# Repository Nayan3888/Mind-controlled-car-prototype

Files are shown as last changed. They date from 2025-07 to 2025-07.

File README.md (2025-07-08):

# 🧠🚗 Mind-Controlled Car using EEG and IoT

A smart **EEG-based Mind-Controlled Car** system that uses the **NeuroSky MindWave Mobile 2** headset to interpret brainwave signals and control an **ESP32-based robot car** via Bluetooth and HTTP protocols. The system also includes **manual control options** using IR remotes and physical buttons, making it a hybrid multi-input system.

---

## 🚀 Project Overview

This project demonstrates how **EEG (Electroencephalography) signals** can be used to control a robotic vehicle. The headset detects **attention, meditation, and blinks**, which are processed in a **Flutter app** to make real-time movement decisions. The car is then controlled via **Wi-Fi (ESP32 HTTP)** based on the detected mental commands.

---

## 🧩 Features

* 🔗 **Real-time EEG signal processing** from NeuroSky MindWave
* 📱 **Flutter mobile app** for Bluetooth communication and UI
* 🌐 **Wi-Fi-based car control** using ESP32 (HTTP GET/POST)
* 👀 **Blink detection** to trigger left/right movement
* 🧘 **Meditation level** to control reverse
* 🚘 Manual controls via:

  * 📡 IR Remote
  * 🔘 Push buttons on PCB
* 📈 Real-time brainwave data graph (Alpha, Beta, Gamma, etc.)
* 🔌 Power-efficient and multi-mode operation

---

## 🛠️ Hardware Components

| Component | Description |
| --- | --- |
| 🧠 NeuroSky MindWave | EEG Headset |
| 🔲 ESP32-WROOM-32 | Microcontroller with Wi-Fi |
| 📱 Android Phone | For Flutter App and EEG parsing |
| 🛞 L298N Motor Driver | For dual DC motor control |
| 🔋 Battery | For powering motors and board |
| 🔘 IR Receiver + Remote | Manual car control |
| 📟 16x2 I2C LCD | (Optional) Display EEG/Status |
| 💧 Moisture/pH Sensor | (Optional extension) |

---

## 📲 Flutter App Features

* Scan and connect to MindWave EEG device (BLE)
* Graphically display EEG metrics (attention, meditation, blink strength)
* Send movement commands to ESP32 via Wi-Fi
* Real-time feedback and alerts

---

## 🔧 How It Works

1. MindWave reads brain signals.
2. Flutter app parses EEG data over Bluetooth using `flutter_blue_plus`.
3. Based on blink or meditation thresholds:

   * Sends commands (e.g., `FORWARD`, `LEFT`, `REVERSE`) to ESP32 via HTTP.
4. ESP32 receives the command and sets motor pins HIGH/LOW using L298N.
5. Manual override is always available via IR or push buttons.

---

## 🧠 EEG Signal Mapping

| EEG Input | Action Triggered |
| --- | --- |
| Blink Detected | Turn Left or Right |
| Meditation > X | Move in Reverse |
| Attention > Y  | Move Forward |
| Idle | Stop |

---

## 🔌 Pin Configuration (ESP32)

| Pin | Description |
| --- | --- |
| D5, D18  | Motor A (Front)  |
| D19, D21 | Motor B (Back) |
| D22 | IR Sensor |
| D23 | Button 1 (Left)  |
| D25 | Button 2 (Right) |
| 3V3, GND | Power Rails |

---

## 📁 Project Structure

```
MindControlledCar/
├── flutter_app/           # EEG data processing & UI
├── esp32_code/            # Arduino code for ESP32
├── pcb_design/            # KiCad schematic & PCB layout
├── images/                # System architecture, demo screenshots
└── README.md              # Project documentation
```

---

## 📷 Demo

PCB Design
Flutter UI
Working Car

---

## 📦 Future Enhancements

* Voice commands as secondary control
* Real-time location tracking using GPS
* Web dashboard with EEG logs
* Adaptive control with ML-based pattern recognition

---

## 🤝 Credits

* **Developed by:** Nayan Parekh ,Ved Patel
* **EEG Hardware:** NeuroSky MindWave Mobile 2
* **Embedded System:** ESP32
* **Mobile App:** Flutter

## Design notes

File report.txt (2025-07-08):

Info: Processing symbol 'R14:Resistor_SMD:R_0603_1608Metric'.
Info: Processing symbol 'R1:Resistor_SMD:R_0603_1608Metric'.
Info: Processing symbol 'C1:Capacitor_SMD:C_1206_3216Metric'.
Info: Processing symbol 'R4:Resistor_SMD:R_0603_1608Metric'.
Info: Processing symbol 'R5:Resistor_SMD:R_0603_1608Metric'.
Info: Processing symbol 'R6:Resistor_SMD:R_0603_1608Metric'.
Info: Processing symbol 'R7:Resistor_SMD:R_0603_1608Metric'.
Info: Processing symbol 'R8:Resistor_SMD:R_0603_1608Metric'.
Info: Processing symbol 'R9:Resistor_SMD:R_0603_1608Metric'.
Info: Processing symbol 'R10:Resistor_SMD:R_0603_1608Metric'.
Info: Processing symbol 'R11:Resistor_SMD:R_0603_1608Metric'.
Info: Processing symbol 'R12:Resistor_SMD:R_0603_1608Metric'.
Info: Processing symbol 'R13:Resistor_SMD:R_0603_1608Metric'.
Info: Processing symbol 'R3:Resistor_SMD:R_0603_1608Metric'.
Info: Processing symbol 'R15:Resistor_SMD:R_0603_1608Metric'.
Info: Processing symbol 'RV1:Potentiometer_THT:Potentiometer_Bourns_3296X_Horizontal'.
Info: Processing symbol 'SW1:Button_Switch_SMD:SW_SPST_EVQP7C'.
Info: Processing symbol 'SW2:Button_Switch_SMD:SW_SPST_EVQP7C'.
Info: Processing symbol 'U1:RF_Module:ESP32-WROOM-32'.
Info: Processing symbol 'U2:Package_TO_SOT_SMD:SOT-223'.
Info: Processing symbol 'U3:Package_TO_SOT_THT:TO-220-15_P2.54x2.54mm_StaggerEven_Lead5.84mm_TabDown'.
Info: Processing symbol 'U4:Package_SO:SOIC-16_3.9x9.9mm_P1.27mm'.
Info: Processing symbol 'U5:Package_SO:SOIC-8-1EP_3.9x4.9mm_P1.27mm_EP2.41x3.3mm_ThermalVias'.
Info: Processing symbol 'U6:Package_TO_SOT_SMD:SOT-23-6'.
Info: Processing symbol 'U7:Package_TO_SOT_SMD:SOT-23-6'.
Info: Total warnings: 1, errors: 0.
Info: Processing symbol 'D4:LED_SMD:LED_0603_1608Metric'.
Info: Processing symbol 'C2:Capacitor_SMD:C_1206_3216Metric'.
Info: Processing symbol 'C3:Capacitor_SMD:C_1206_3216Metric'.
Info: Processing symbol 'C4:Capacitor_SMD:C_1206_3216Metric'.
Info: Processing symbol 'C5:Capacitor_SMD:C_1206_3216Metric'.
Info: Processing symbol 'C6:Capacitor_SMD:C_1206_3216Metric'.
Info: Processing symbol 'C7:Capacitor_SMD:C_1206_3216Metric'.
Info: Processing symbol 'C8:Capacitor_SMD:C_1206_3216Metric'.
Info: Processing symbol 'C9:Capacitor_SMD:C_1206_3216Metric'.
Info: Processing symbol 'D2:LED_SMD:LED_0603_1608Metric'.
Info: Processing symbol 'D3:LED_SMD:LED_0603_1608Metric'.
Info: Processing symbol 'Q2:Package_TO_SOT_SMD:SOT-23'.
Info: Processing symbol 'D5:LED_SMD:LED_0603_1608Metric'.
Info: Processing symbol 'D6:LED_SMD:LED_0603_1608Metric'.
Info: Processing symbol 'D7:LED_SMD:LED_0603_1608Metric'.
Info: Processing symbol 'D8:LED_SMD:LED_0603_1608Metric'.
Info: Processing symbol 'D9:Diode_SMD:D_SMA'.
Info: Processing symbol 'J1_+1:Connector_JST:JST_EH_S2B-EH_1x02_P2.50mm_Horizontal'.
Info: Processing symbol 'J2:Connector_JST:JST_EH_S2B-EH_1x02_P2.50mm_Horizontal'.
Info: Processing symbol 'J3:Connector_JST:JST_EH_S4B-EH_1x04_P2.50mm_Horizontal'.
Info: Processing symbol 'J4:Connector_JST:JST_EH_S2B-EH_1x02_P2.50mm_Horizontal'.
Info: Processing symbol 'J5:Connector_JST:JST_EH_S2B-EH_1x02_P2.50mm_Horizontal'.
Info: Processing symbol 'J8:Connector_USB:USB_Micro-B_Amphenol_10103594-0001LF_Horizontal'.
Info: Processing symbol 'L1:Inductor_SMD:L_1210_3225Metric'.
Info: Processing symbol 'Q1:Package_TO_SOT_SMD:SOT-23'.

Warning: No net found for component U2 pad 4 (no pin 4 in symbol).

Info: Total warnings: 1, errors: 0.

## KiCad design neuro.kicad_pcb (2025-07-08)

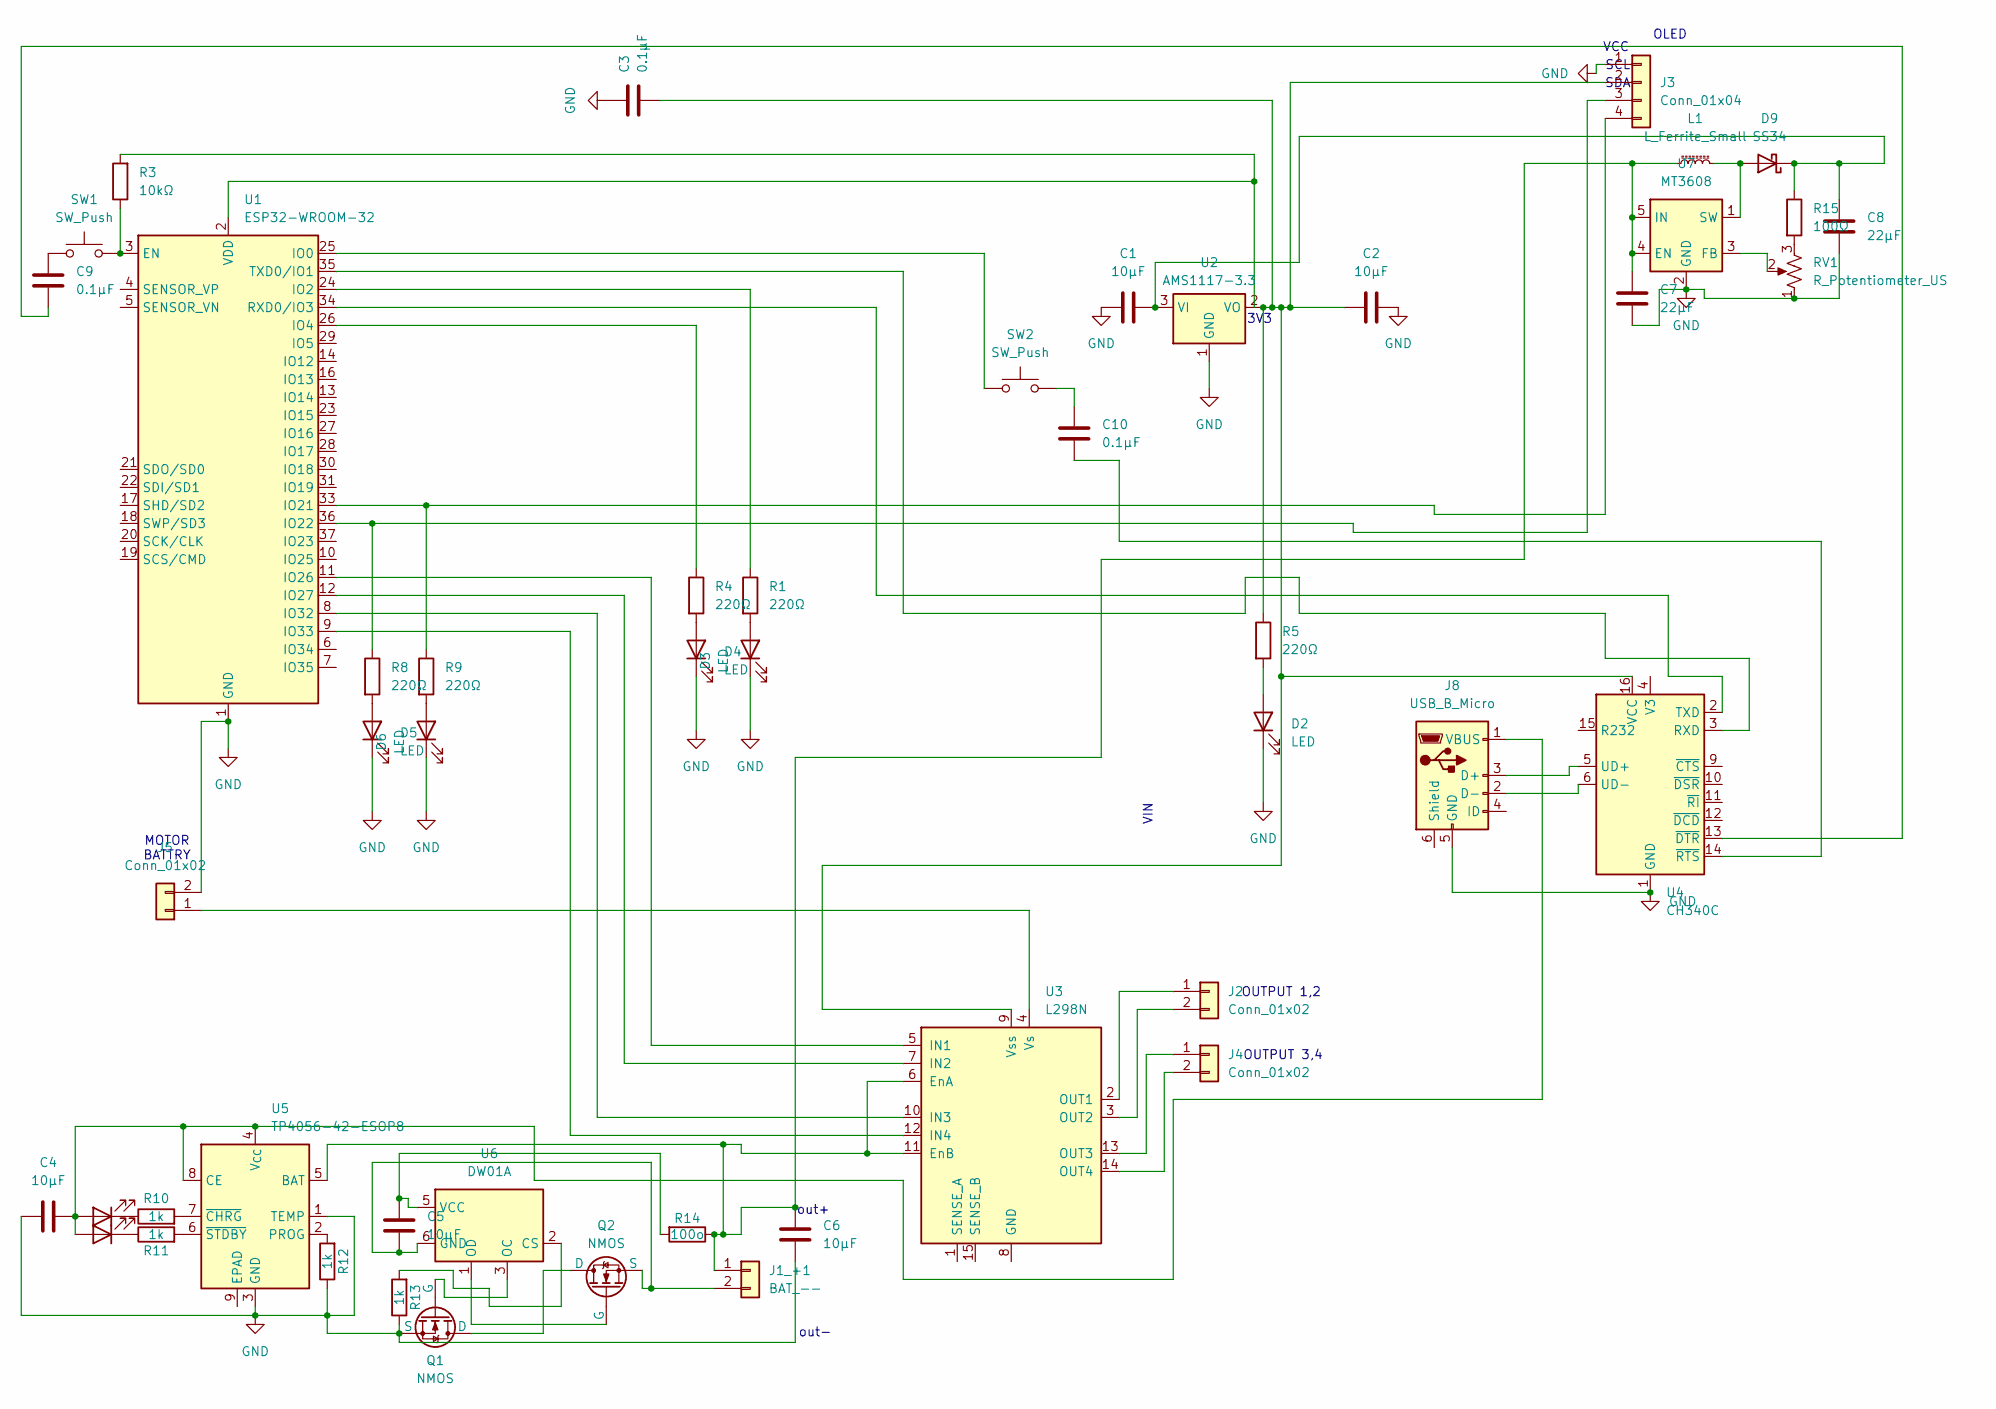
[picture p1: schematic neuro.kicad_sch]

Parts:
C1, C2, C4, C5, C6: 10µF; C_1206_3216Metric
C3, C9, C10: 0.1µF; C_1206_3216Metric
C7, C8: 22µF; C_1206_3216Metric
D2, D3, D4, D5, D6, D7, D8: LED; LED_0603_1608Metric
D9: SS34; D_SMA
J1_+1: BAT_--; JST_EH_S2B-EH_1x02_P2.50mm_Horizontal
J2, J4, J5: Conn_01x02; JST_EH_S2B-EH_1x02_P2.50mm_Horizontal
J3: Conn_01x04; JST_EH_S4B-EH_1x04_P2.50mm_Horizontal
J8: USB_B_Micro; USB_Micro-B_Amphenol_10103594-0001LF_Horizontal
L1: L_Ferrite_Small; L_1210_3225Metric
Q1, Q2: NMOS; SOT-23
R1, R4, R5, R8, R9: 220Ω; R_0603_1608Metric
R3: 10kΩ; R_0603_1608Metric
R10, R11, R12, R13: 1k; R_0603_1608Metric
R14: 100o; R_0603_1608Metric
R15: 100Ω; R_0603_1608Metric
RV1: R_Potentiometer_US; Potentiometer_Bourns_3296Y_Vertical
SW1, SW2: SW_Push; SW_SPST_EVQP7C
U1: ESP32-WROOM-32
U2: AMS1117-3.3; SOT-223
U3: L298N; TO-220-15_P2.54x5.08mm_StaggerEven_Lead4.58mm_Vertical
U4: CH340C; SOIC-16_3.9x9.9mm_P1.27mm
U5: TP4056-42-ESOP8; SOIC-8-1EP_3.9x4.9mm_P1.27mm_EP2.41x3.3mm_ThermalVias
U6: DW01A; SOT-23-6
U7: MT3608; SOT-23-6

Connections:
GND: C1.1, C2.2, C3.1, C4.1, C6.1, C7.1, C8.1, D2.1 (K), D3.1 (K), D4.1 (K), D5.1 (K), D6.1 (K), J3.1, J5.2, J8.5 (GND), Q1.3 (S), R12.1, R13.1, RV1.1, U1.1 (GND), U1.15 (GND), U1.38 (GND), U1.39 (GND), U2.1 (GND), U4.1 (GND), U5.1 (TEMP), U5.3 (GND), U7.2 (GND)
unnamed: C9.2, SW1.1
unnamed: C10.2, SW2.2
unnamed: D2.2 (A), R5.2
unnamed: D3.2 (A), R1.2
unnamed: D4.2 (A), R4.2
unnamed: D5.2 (A), R8.2
unnamed: D6.2 (A), R9.2
unnamed: C4.2, D7.2 (A), D8.2 (A), J8.1 (VBUS), U5.4 (V_{CC}), U5.8 (CE)
unnamed: D7.1 (K), R10.1
unnamed: D8.1 (K), R11.1
unnamed: D9.2 (A), L1.2, U7.1 (SW)
unnamed: C1.2, C8.2, D9.1 (K), R15.1, U2.3 (VI)
unnamed: C6.2, C7.2, J1_+1.1, L1.1, R14.1, U3.6 (EnA), U3.11 (EnB), U5.5 (BAT), U7.4 (EN), U7.5 (IN)
unnamed: C5.1, J1_+1.2, Q2.3 (S), U6.6 (GND)
unnamed: J2.1, U3.2 (OUT1)
unnamed: J2.2, U3.3 (OUT2)
unnamed 17: C2.1, C3.2, J3.2, R5.1, U2.2 (VO), U3.9 (Vss), U4.16 (VCC); also elsewhere on the board
unnamed 18: J3.3, R8.1, U1.36 (IO22); also elsewhere on the board
unnamed 19: J3.4, R9.1, U1.33 (IO21); also elsewhere on the board
unnamed: J4.1, U3.13 (OUT3)
unnamed: J4.2, U3.14 (OUT4)
unnamed: J5.1, U3.4 (Vs)
unnamed: J8.3 (D+), U4.5 (UD+)
unnamed: J8.2 (D-), U4.6 (UD-)
unnamed: Q1.1 (D), Q2.1 (D)
unnamed: Q1.2 (G), U6.3 (OC)
unnamed: Q2.2 (G), U6.1 (OD)
unnamed: R15.2, RV1.3
unnamed: R3.1, SW1.2, U1.3 (EN)
unnamed: SW2.1, U1.25 (IO0)
unnamed: R1.1, U1.24 (IO2)
unnamed: R4.1, U1.26 (IO4)
unnamed: U1.11 (IO26), U3.5 (IN1)
unnamed: U1.12 (IO27), U3.7 (IN2)
unnamed: U1.8 (IO32), U3.10 (IN3)
unnamed: U1.9 (IO33), U3.12 (IN4)
unnamed: U1.34 (RXD0/IO3), U4.2 (TXD)
unnamed: U1.35 (TXD0/IO1), U4.3 (RXD)
unnamed: R3.2, U1.2 (VDD)
unnamed: C9.1, U4.13 (~DTR)
unnamed: C10.1, U4.14 (~RTS)
unnamed: R12.2, U5.2 (PROG)
unnamed: R10.2, U5.7 (~CHRG)
unnamed: R11.2, U5.6 (~STDBY)
unnamed: R13.2, U6.2 (CS)
unnamed: C5.2, R14.2, U6.5 (VCC)
unnamed: RV1.2, U7.3 (FB)

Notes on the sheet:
OUTPUT 3,4
MOTOR BATTRY
3V3
SDA
SCL
out+
OUTPUT 1,2
OLED
out-
VCC
VIN

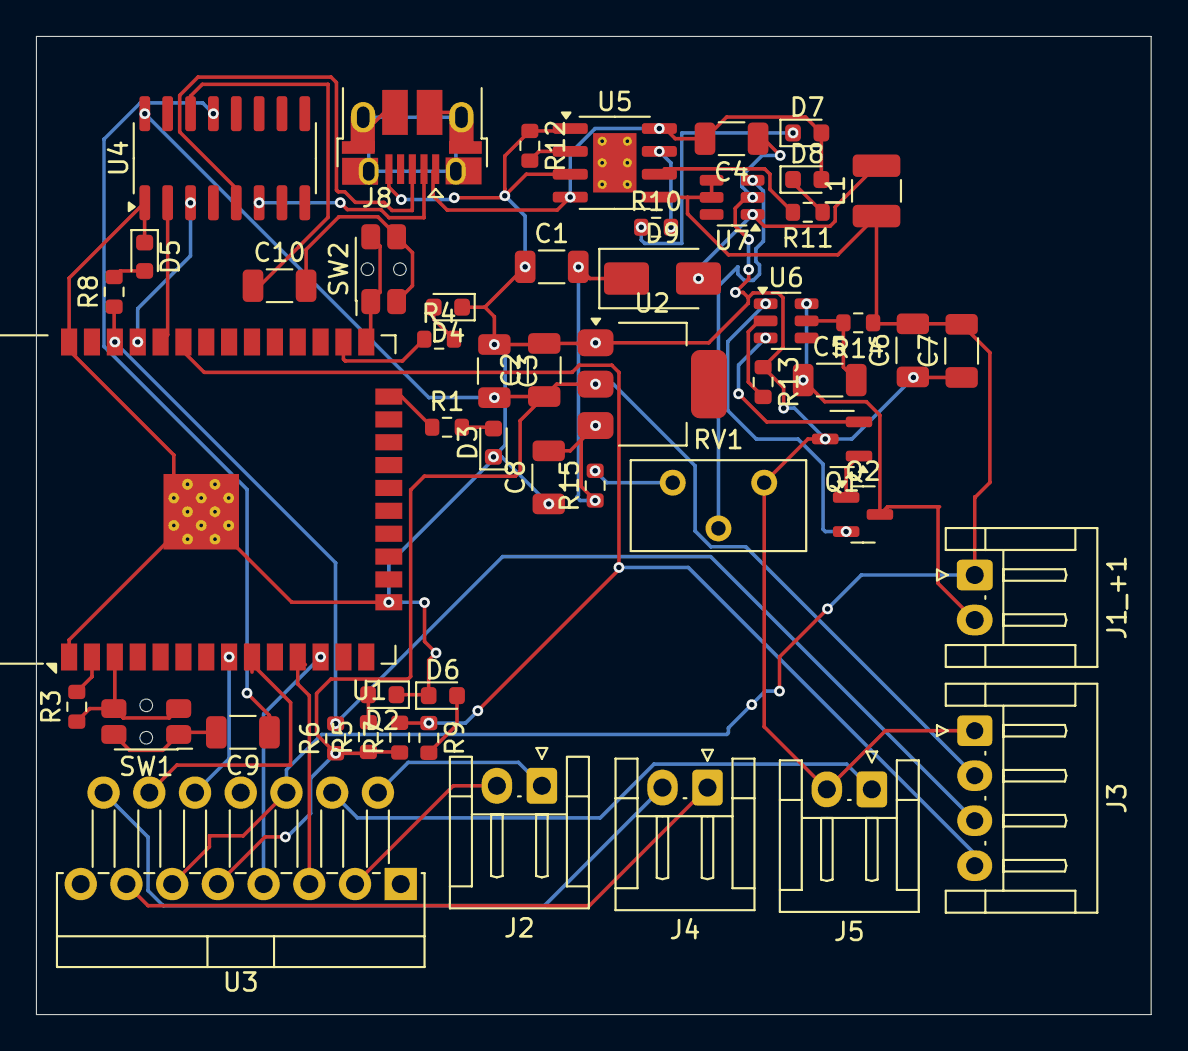
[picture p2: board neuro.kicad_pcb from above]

Board: 2 copper layers, 61.9 x 54.3 mm, 51 parts (0 on the bottom side), 48 nets.

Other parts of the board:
R6, R7: 10kΩ; R_0603_1608Metric

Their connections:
unnamed 17: R6.1, R7.1; also elsewhere on the board
unnamed 18: R6.2; also elsewhere on the board
unnamed 19: R7.2; also elsewhere on the board
